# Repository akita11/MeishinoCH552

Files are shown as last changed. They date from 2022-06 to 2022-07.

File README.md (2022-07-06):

# MeishinoCH552

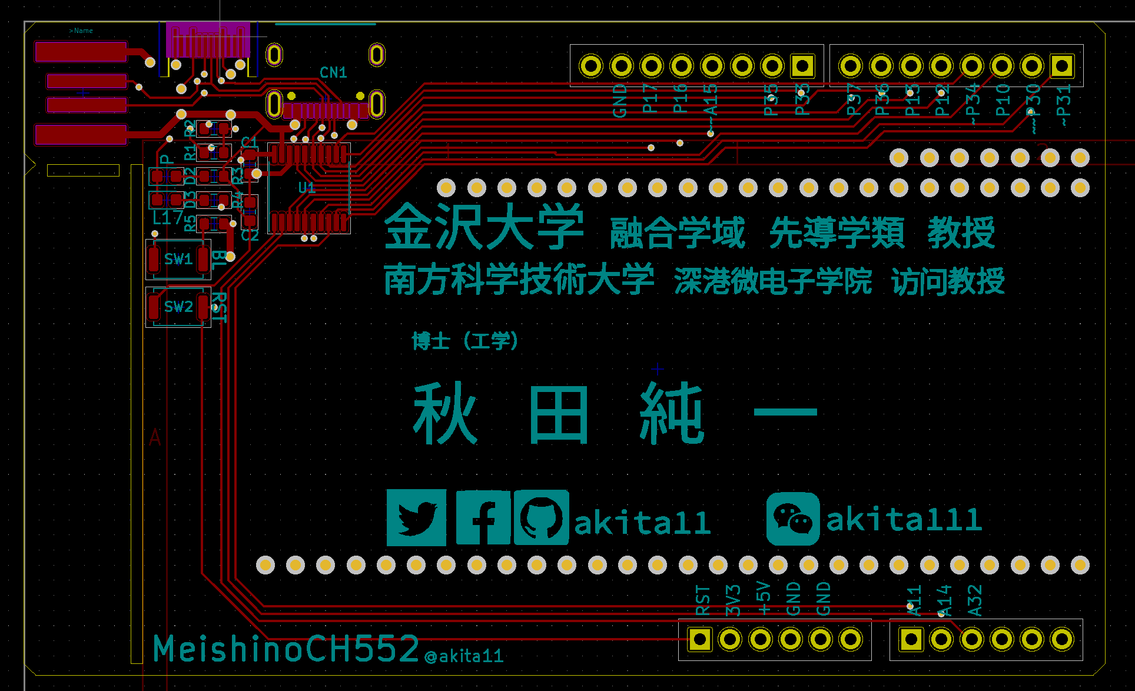
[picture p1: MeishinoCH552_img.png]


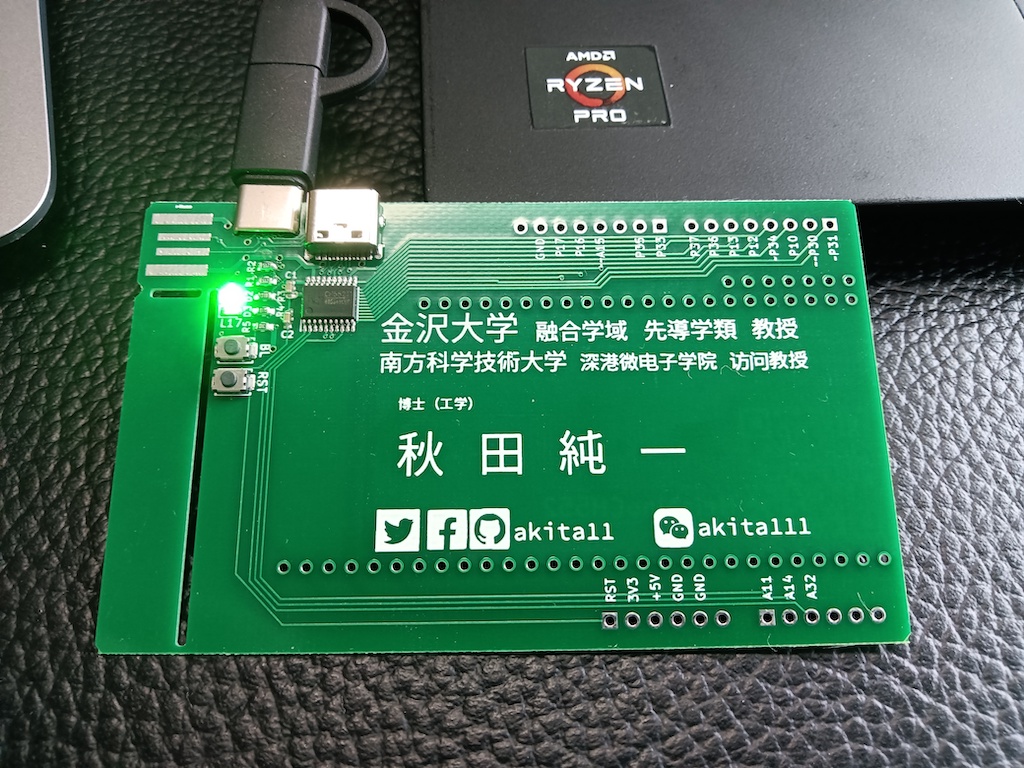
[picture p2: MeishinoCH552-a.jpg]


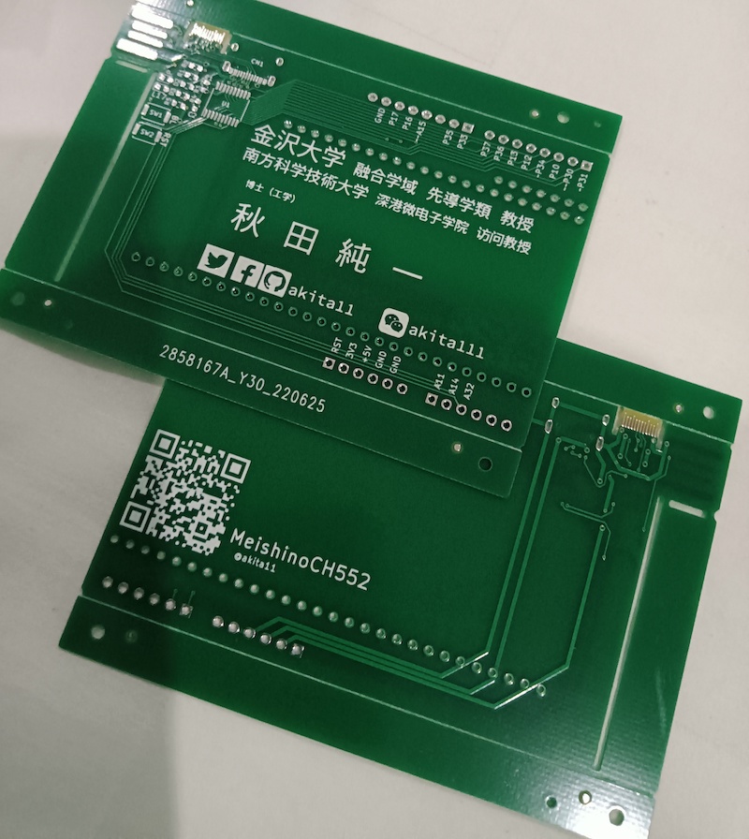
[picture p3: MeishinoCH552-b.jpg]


つくった基板を名刺代わりに！

基板の表や裏の空いているところに、自分の名前などをシルクで入れれば、オリジナル基板のできあがり。
あとは製造発注して、名刺代わりに配りましょう。

## マイコンボードとしての使い方

基板製造時に部品実装(PCBA)もいっしょに注文すれば、ArduinoIDEでプログラムを書けるマイコンボードとしても使えます。もちろん自分で部品をはんだ付けしてもOK。
（[CH552duino](https://github.com/akita11/CH552duino)と同じ構成ですので、これの使い方を参照してください。[使い方を含めた解説書](https://techbookfest.org/product/5803512929714176)もあります。）

PCにつなぐUSB端子は、以下の3つのいずれかを使えます。

- 基板の一部にあるUSB端子を直接PCへ（USB端子の周りの板を切り取って使います。（※板厚2.0mm。それより薄い場合は厚紙などをはさむ）
- 基板上部にあるUSB Type-C端子にUSB Type-Cケーブルで接続（※板厚0.6mm）
- 基板上にUSB Type-Cコネクタを実装し、USB Type-Cケーブルで接続

## オリジナル基板のつくりから

プリント基板設計CADの[KiCAD](https://www.kicad.org/)で名前などを記入し、オリジナル基板をつくることができます。
文字だけでなく、画像を入れることもできます。名前などが書かれた画像データを用意します。例してPowerPointファイル(namecard.pptx)を用意してあります。この枠内をスクリーンショットで保存するのが簡単でいいでしょう。

画像データはKiCADの"Bitmap Converter"で、KiCADで使える部品（フットプリント）に変換してから、基板に読み込んで配置すればOKです。例として、名前などを入れたもの（MeishinoCH552_sample.kicad_pcb）を用意してありますので参考にしてください。

# 基板の製造

製造用ガーバーデータ（MeishinoCH552_gerber.zip：ただし名前などは何も入っていない）を使うか、[KiCAD](https://www.kicad.org/)で設計したものから製造用ガーバーデータを出力します。

基板製造は、[JLCPCB](https://jlcpcb.com/)などのオンラインサービスを使うと便利です。

基板の色（レジスト）は自由です。基板上部のUSB Type-C端子を使うためには、板厚は0.6mmとしてください（これを使わない場合は板厚は自由）。

# 部品の調達と実装

部品表（MeishinoCH552_BOM_JLCSMT.xlsx）の部品を[LCSC](https://lcsc.com/)などで購入し、手ハンダなどの方法で部品を実装します。あるいは、この部品表を部品位置ファイル（MeishinoCH552_CPL_JLCSMT.xlsx）とともに[JLCPCB](https://jlcpcb.com/)に注文すれば、部品実装が済んだ状態のものを得ることもできます。

※実際にPCBAを発注する際は、BOMとCPLの内容をよく確認してください。指定している部品が在庫切れの場合や、部品の実装位置・向きが実際とズレている場合があります（これは部品の0度の向きの定義が明確ではないことから生じる不確実性です）ので、ビューア等でよく確認をしてください。

なおUSB Type-Cコネクタを実装せずに、基板パターンを活用したUSB Type-CコネクタにUSBケーブルを接続して使用することにすれば、全体の厚さを2mm程度にすることができます。（ただし何回も抜き差しするとコネクタ部の基板パターンが摩耗により劣化します）

# Author

Junichi Akita (@akita11, akita@ifdl.jp)

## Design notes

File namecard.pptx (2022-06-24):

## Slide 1

金沢大学 融合学域 先導学類 教授
南方科学技術大学 深港微电子学院 访问教授

秋 田 純 一

博士（工学）

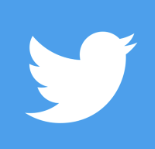
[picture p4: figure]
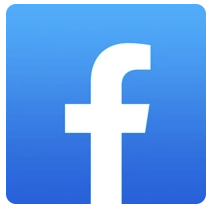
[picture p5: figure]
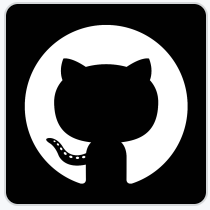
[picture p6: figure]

akita11

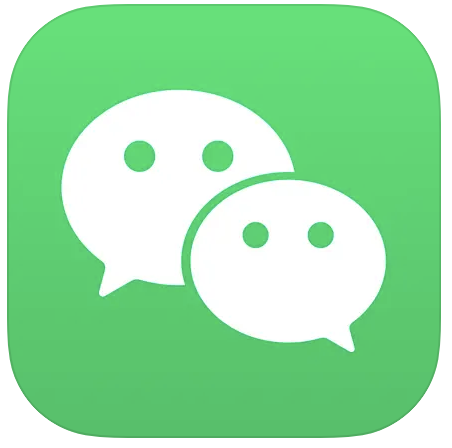
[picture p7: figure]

akita111

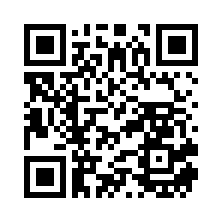
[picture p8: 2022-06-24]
URL_QR.png

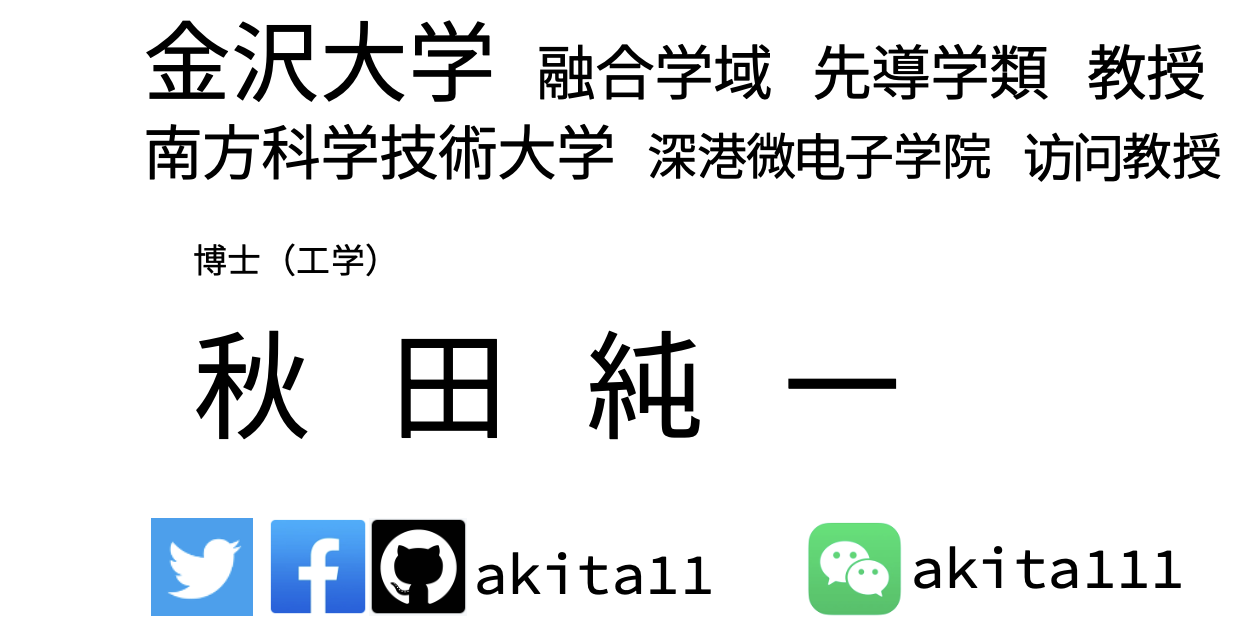
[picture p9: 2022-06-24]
namecard.png

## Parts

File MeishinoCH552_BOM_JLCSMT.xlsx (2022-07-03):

Comment | Designator | Footprint | JLCPCB Part #（optional）
0.1u | C1,C2 | C0603 | C14663
CH552T | U1 | TSSO20 | C111367
USB TypeC | CN1 | TYPE-C-31_L8.94_W7.3 | C165948
TactSW | SW2,SW1 | SMD,3.9x2.9x2mm | C2837082
LED(G) | D2 | D0603 | C12624 | 明るすぎるので在庫あればC138548のほうがよい
LED(Y) | D3 | D0603 | C138546
1k | R4,R3 | R0603 | C21190
10k | R5 | R0603 | C25804
5.1k | R1,R2 | R0603 | C23186

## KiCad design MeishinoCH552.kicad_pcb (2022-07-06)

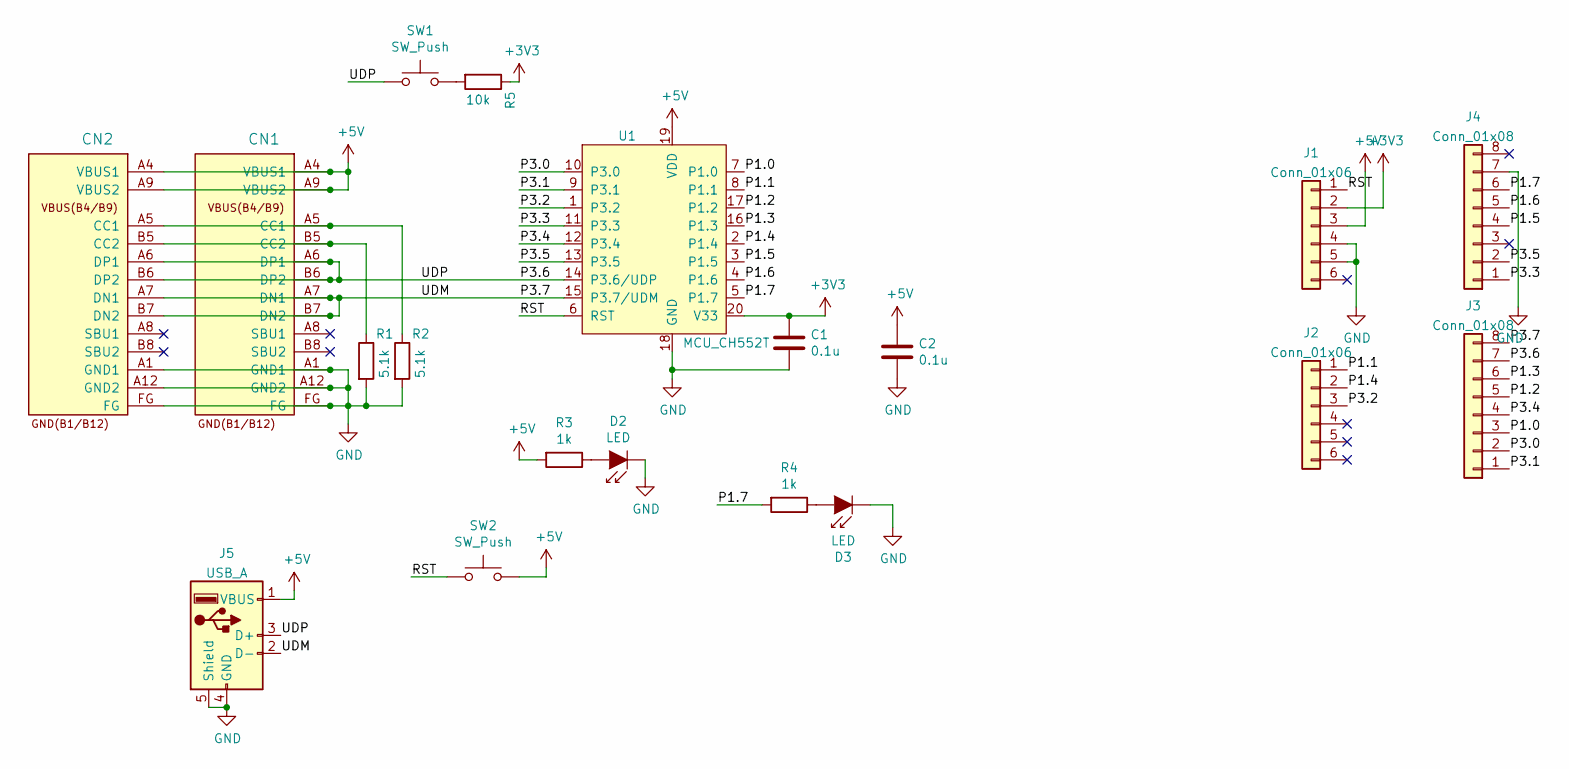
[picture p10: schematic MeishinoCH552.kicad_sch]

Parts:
C1, C2: 0.1u; C_0603_1608Metric
CN1: CON_USB-C-16; USB-C_16P_TH
CN2: CON_USB-C-16; USB-C_PCBPLUG
D2, D3: LED; LED_0603_1608Metric
J1, J2: Conn_01x06; PinSocket_1x06_P2.54mm_Vertical
J3, J4: Conn_01x08; PinSocket_1x08_P2.54mm_Vertical
J5: USB_A; USB-A-PCB
R1, R2: 5.1k; R_0603_1608Metric
R3, R4: 1k; R_0603_1608Metric
R5: 10k; R_0603_1608Metric
SW1, SW2: SW_Push; SW_Push_SPST_NO_Alps_SKRK
U1: MCU_CH552T; TSSOP-20_4.4x6.5mm_P0.65mm

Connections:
+3V3: C1.1, J1.2, R5.1, U1.20 (V33)
+5V: C2.1, CN1.A4 (VBUS1), CN1.A9 (VBUS2), CN2.A4 (VBUS1), CN2.A9 (VBUS2), J1.3, J5.1 (VBUS), R3.2, SW2.2, U1.19 (VDD)
/P1.0: J3.3, U1.7 (P1.0)
/P1.1: J2.1, U1.8 (P1.1)
/P1.2: J3.5, U1.17 (P1.2)
/P1.3: J3.6, U1.16 (P1.3)
/P1.4: J2.2, U1.2 (P1.4)
/P1.5: J4.4, U1.3 (P1.5)
/P1.6: J4.5, U1.4 (P1.6)
/P1.7: J4.6, R4.2, U1.5 (P1.7)
/P3.0: J3.2, U1.10 (P3.0)
/P3.1: J3.1, U1.9 (P3.1)
/P3.2: J2.3, U1.1 (P3.2)
/P3.3: J4.1, U1.11 (P3.3)
/P3.4: J3.4, U1.12 (P3.4)
/P3.5: J4.2, U1.13 (P3.5)
/P3.6: CN1.A6 (DP1), CN1.B6 (DP2), CN2.A6 (DP1), CN2.B6 (DP2), J3.7, J5.3 (D+), SW1.1, U1.14 (P3.6/UDP)
/P3.7: CN1.A7 (DN1), CN1.B7 (DN2), CN2.A7 (DN1), CN2.B7 (DN2), J3.8, J5.2 (D-), U1.15 (P3.7/UDM)
/RST: J1.1, SW2.1, U1.6 (RST)
GND: C1.2, C2.2, CN1.A1 (GND1), CN1.A12 (GND2), CN1.FG, CN2.A1 (GND1), CN2.A12 (GND2), CN2.FG, D2.1 (K), D3.1 (K), J1.4, J1.5, J4.7, J5.4 (GND), J5.5 (Shield), R1.2, R2.2, U1.18 (GND)
unnamed: CN1.A5 (CC1), CN2.A5 (CC1), R2.1
unnamed: CN1.B5 (CC2), CN2.B5 (CC2), R1.1
unnamed: D2.2 (A), R3.1
unnamed: D3.2 (A), R4.1
unnamed: R5.2, SW1.2

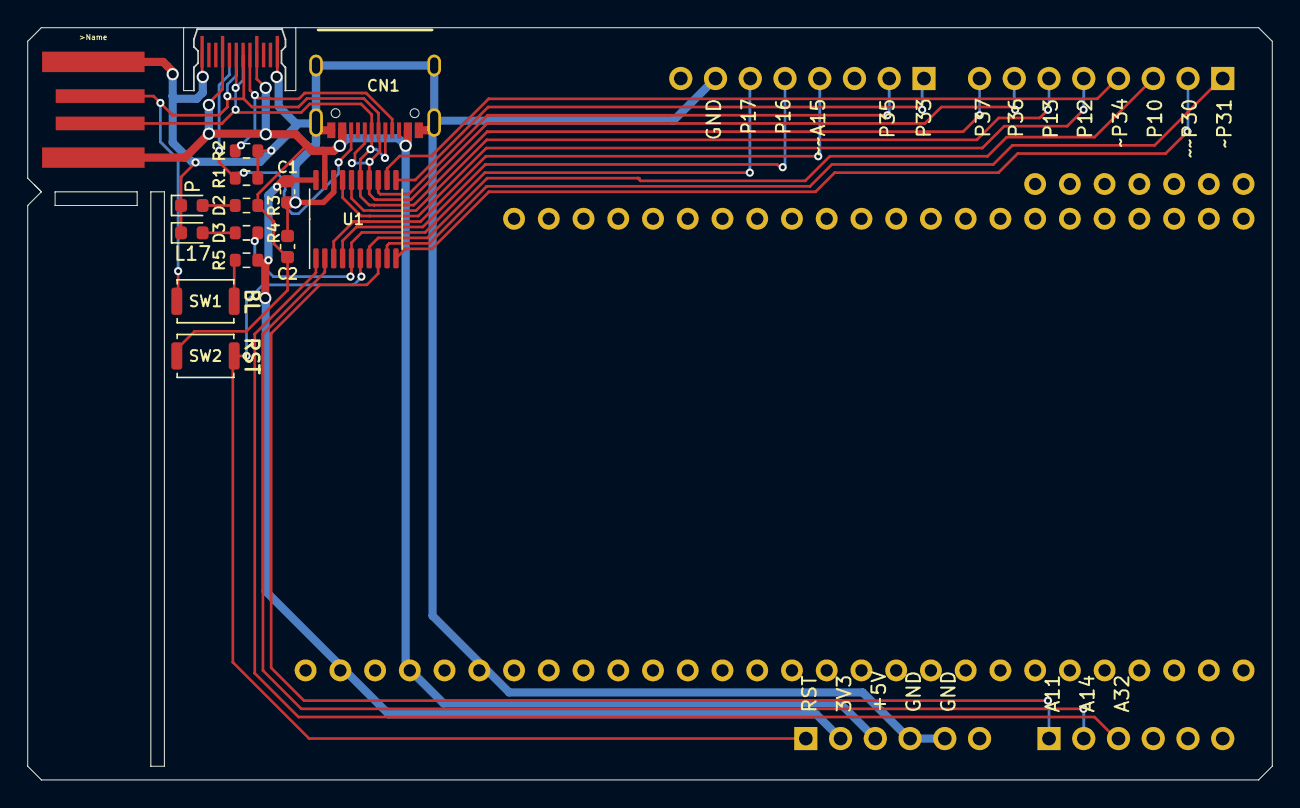
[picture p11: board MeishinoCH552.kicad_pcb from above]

Board: 2 copper layers, 91.0 x 55.0 mm, 19 parts (0 on the bottom side), 25 nets.

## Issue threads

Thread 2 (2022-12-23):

ご質問

ASEIITO, 2022-12-23:
こんにちは！この名刺、素晴らしいのです。ただ、自分で実装するのが難しそうです。仮に「部品実装が済んだ状態のものを得る」といくらくらいかかるものなのでしょうか？くだらないご質問で申し訳ございません。

akita11, 2022-12-26:
いま試しに5枚で見積もりだしてみたら、概略は以下の通り32USDほどでした。枚数を増やす場合は、初期費用は同じ、部品代＋実装は枚数に比例、基板（板）の費用も、ほぼ枚数に比例、と考えていただくといいです。（これに送料がかかる）

- 初期費用=10USD
- 基板（板）=2USD
- 部品代＋実装＝20USD

ASEIITO, 2022-12-27:
ご教示ありがとうございます！イメージがつきました。

akita11, 2022-12-27:
ちなみに部品なしの基板だけだと、2USDと送料だけ、でいけます

ASEIITO, 2022-12-27:
確かにそれでも十分魅力的ですね、、、。

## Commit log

2022-07-03 BOM bug fix
    [MeishinoCH552_BOM_JLCSMT.xlsx]
2022-07-03 add PCB photo
2022-07-03 PCBA発注時の注意を追加
2022-07-06 フリー配線エリアのパッドをレジストなしに
    [MeishinoCH552.kicad_pcb]
